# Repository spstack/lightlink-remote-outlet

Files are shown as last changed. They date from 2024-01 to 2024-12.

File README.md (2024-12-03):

# Light Link

A way to remotely link power outlets! This is an idea taken from the "Switcheroo" device that allows taking an existing switched 
power outlet and linking it wirelessly with another outlet. 

Basically, you can change the location of an outlet that is already hooked up to a switch. The device uses a simple 915MHz wireless
transceiver so there's no wifi/bluetooth involved. You just select the channel you want to control and if any device on 
that channel is powered on or off, all of the devices on that channel will follow it.

It's really useful for me in an apartment where you can't change the wiring (or just don't want to). I made about 10 of these devices to
use in multiple locations where there's a switched outlet.

| | | 
|---|---|
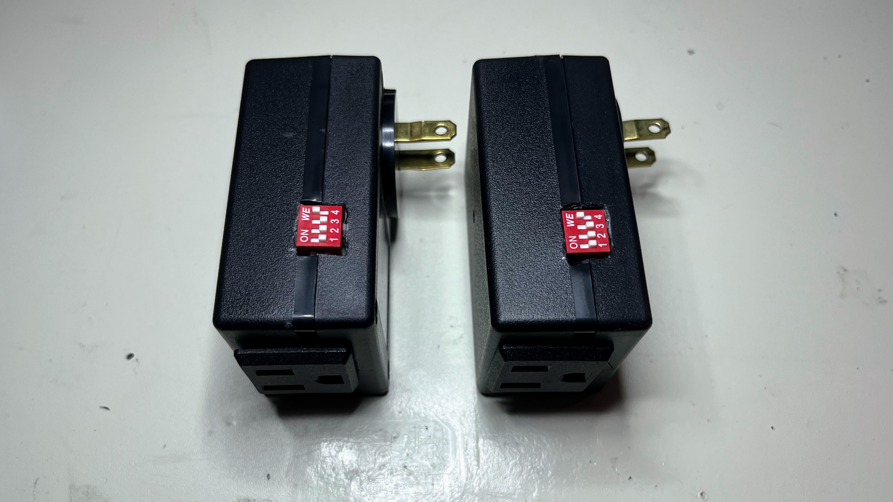
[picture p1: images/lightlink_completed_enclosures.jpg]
Light Link Enclosures
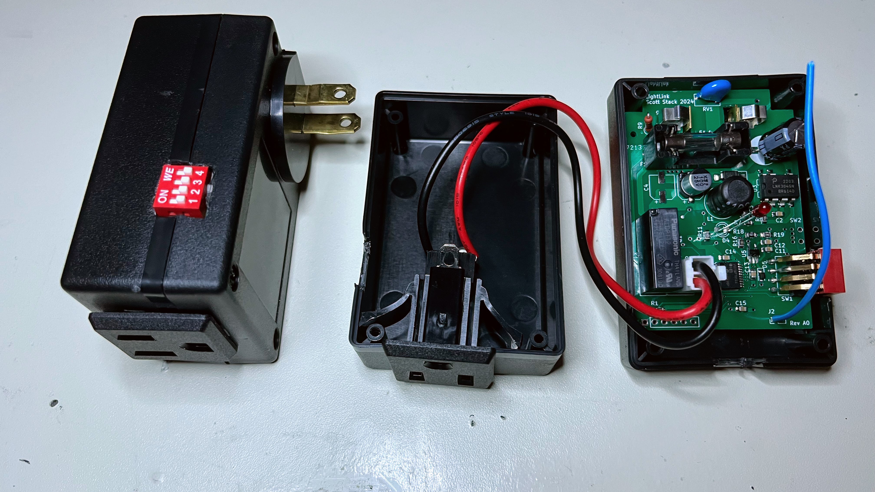
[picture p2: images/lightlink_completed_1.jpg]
Light Link Completed1
| |  |

## Board Design

The board was designed in KiCAD and manufactured by JLC PCB. The main components are a PIC microcontroller connected to an RFM69HCW
wireless transciever. There's also a relay connected to the live end of the incoming mains voltage and a small set of DIP switches for
selecting which channel to transmit on.

The power system is somewhat interesting. A 12V rail is generated through a simple switching regulator that's designed to replace 
capacitive dropper circuits (small amount of current). This rail contains some very large electrolytic capacitors that serve to store energy
and power the rest of the system for a small amount of time when mains voltage is lost. This 12V rail feeds into a second DC-DC switching regulator that powers
the digital electronics. If the 12V rail drops below a threshold, a signal is sent to the PIC to transmit the "power down" command
to all other LightLinks on it's channel.

Schematic Sheet 1 | Schematic Sheet 2 
|-----------------|--------------------|
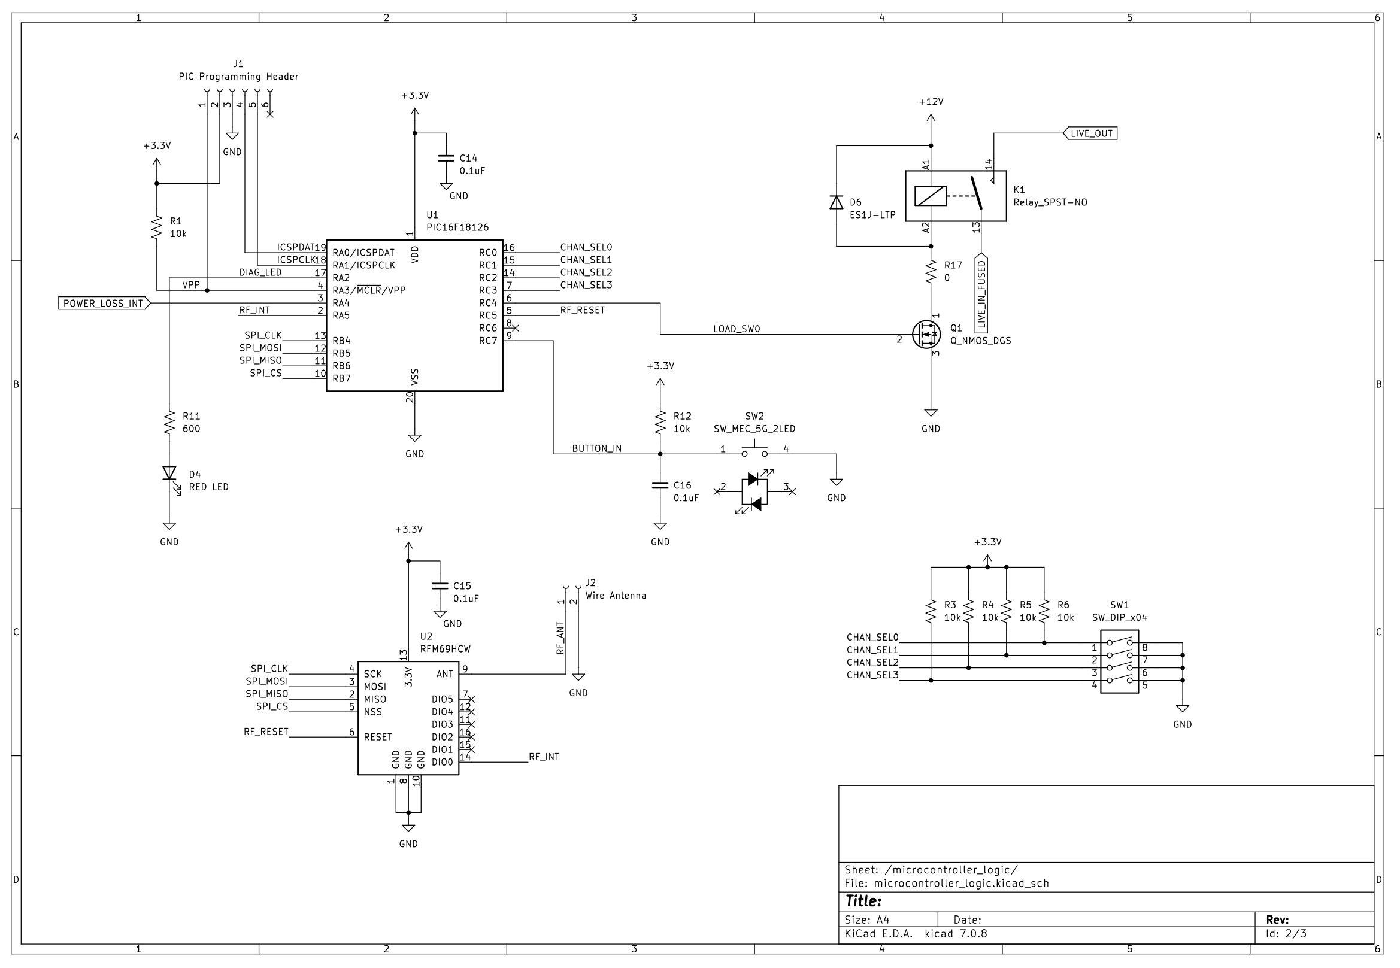
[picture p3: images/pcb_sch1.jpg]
LightLink Sch 1
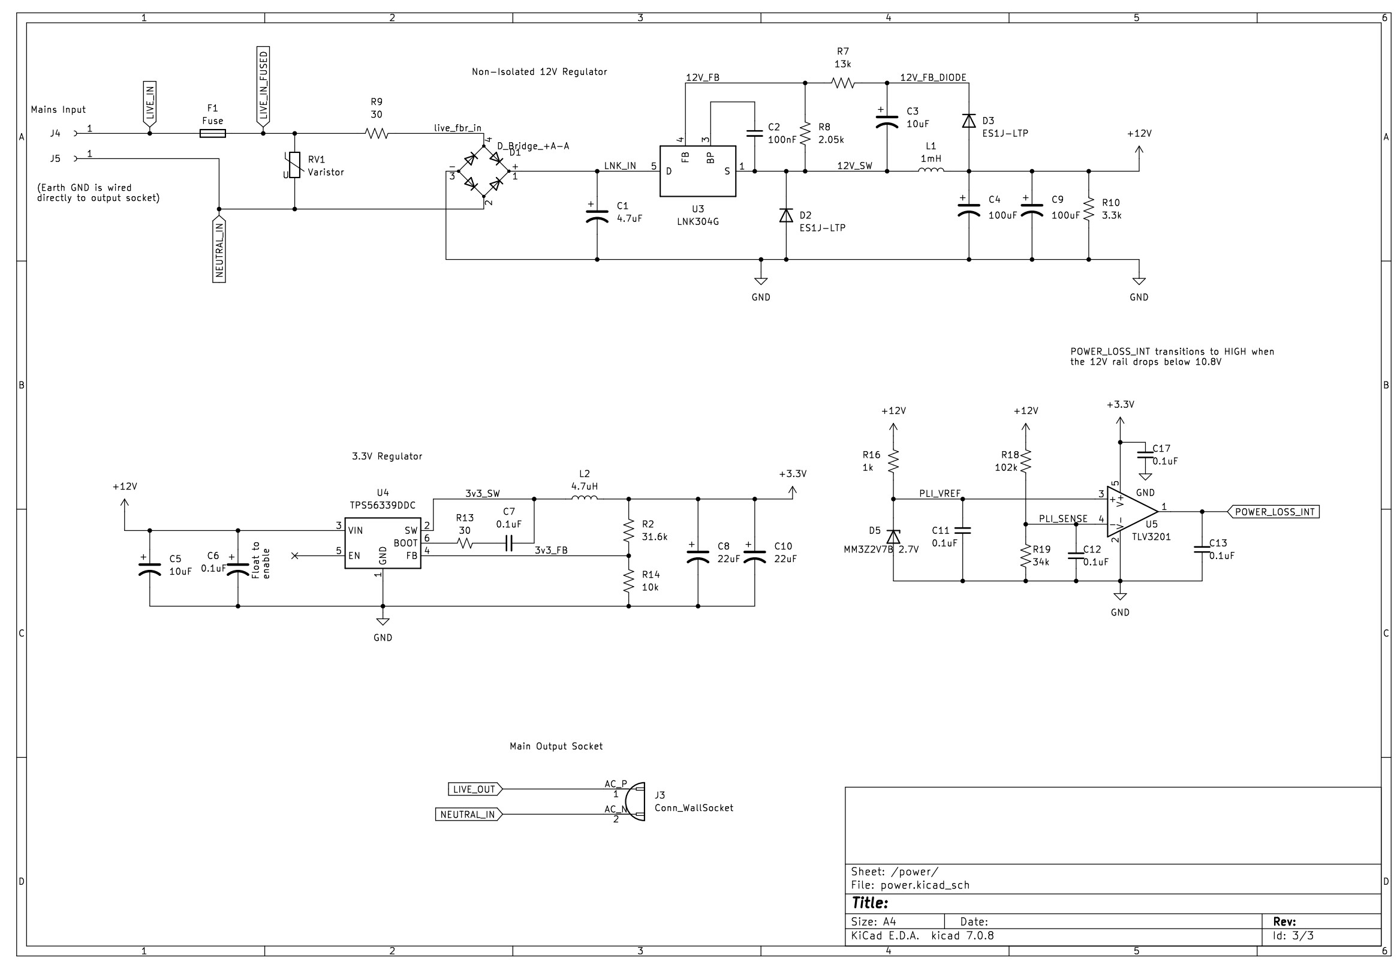
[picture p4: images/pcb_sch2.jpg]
LightLink Sch 2
||  |

Board Layout Front | Board Layout Back 
|-----------------|--------------------|
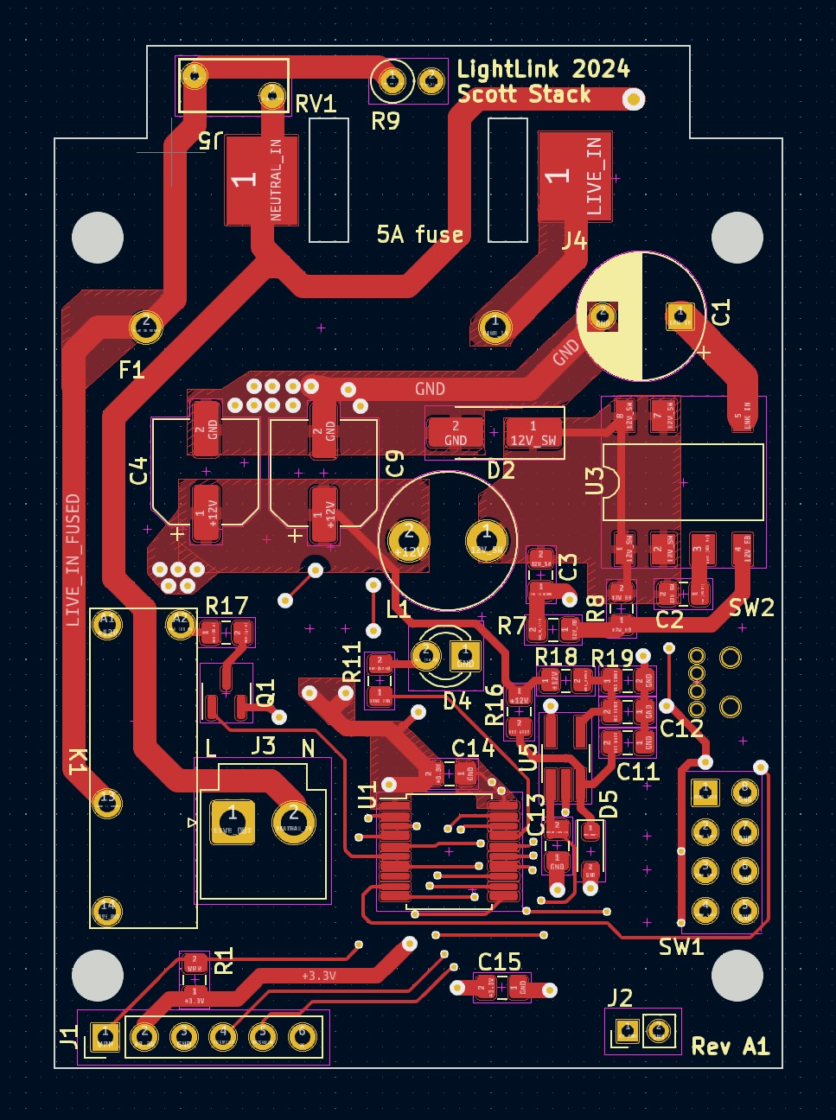
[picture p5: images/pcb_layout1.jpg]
Board Layout 1
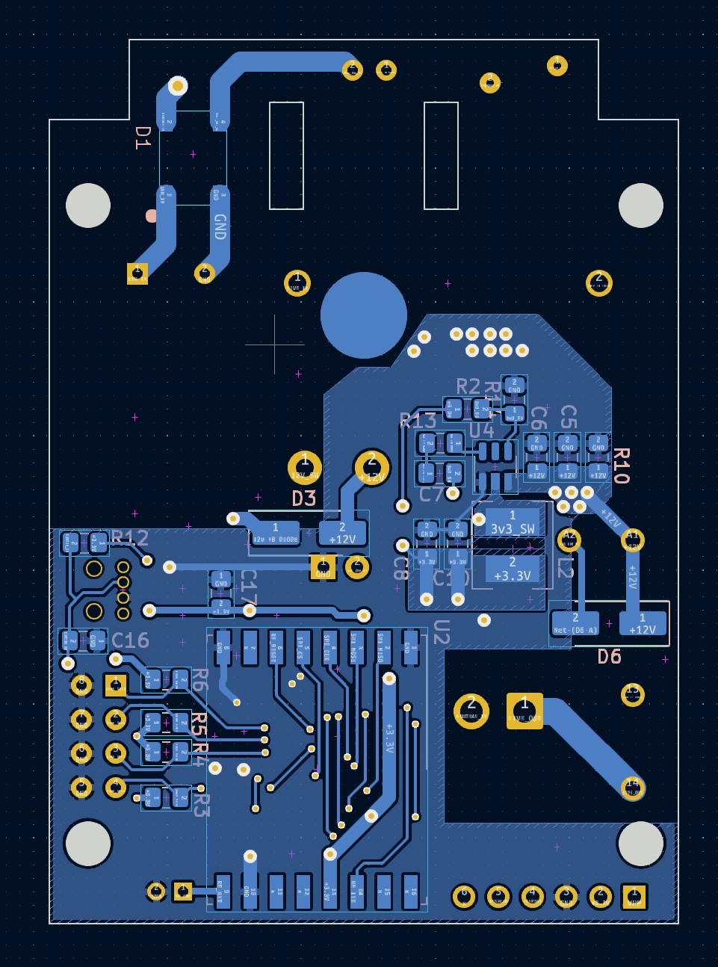
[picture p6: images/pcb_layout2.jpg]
Board Layout 2
| |  |

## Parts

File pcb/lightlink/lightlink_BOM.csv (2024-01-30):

Source: | C:\Users\Scott\Dropbox\my documents\Projects_and_Misc_Tech\1_PROJECTS\RF_OutletRemote\RemoteOutlet\RemoteOutlet.kicad_sch
Date: | 1/25/2024 11:15:09 PM
Tool: | Eeschema 7.0.8
Generator: | C:\Program Files\KiCad\7.0\bin\scripting\plugins/bom_csv_grouped_by_value.py
Component Count: | 58
Collated Components:
Item | Qty | Reference(s) | Value | LibPart | Footprint | Datasheet | DNP | ForwardVoltageDrop | PN | Part | Sim.Device | Sim.Library | Sim.Name | Sim.Params | Sim.Pins | Voltage
="1" | 1 | C1 | 4.7uF | Device:C_Polarized_US | Capacitor_THT:CP_Radial_D8.0mm_P5.00mm | ~
="2" | 1 | C2 | 100nF | Device:C_Small | Capacitor_SMD:C_0805_2012Metric_Pad1.18x1.45mm_HandSolder | ~
="3" | 2 | C3, C5 | 10uF | Device:C_Polarized_US | Capacitor_SMD:C_1206_3216Metric_Pad1.33x1.80mm_HandSolder | ~ |  |  |  |  |  |  |  |  |  | 35V
="4" | 2 | C4, C9 | 100uF | Device:C_Polarized_US | Capacitor_SMD:CP_Elec_6.3x7.7 | ~ |  |  |  |  |  |  |  |  |  | 35V
="5" | 1 | C6 | 0.1uF | Device:C_Polarized_US | Capacitor_SMD:C_0805_2012Metric_Pad1.18x1.45mm_HandSolder | ~
="6" | 7 | C7, C11, C12, C13, C14, C15, C16 | 0.1uF | Device:C_Small | Capacitor_SMD:C_0805_2012Metric_Pad1.18x1.45mm_HandSolder | ~
="7" | 2 | C8, C10 | 22uF | Device:C_Polarized_US | Capacitor_SMD:C_0805_2012Metric_Pad1.18x1.45mm_HandSolder | ~
="8" | 1 | D1 | D_Bridge_+A-A | Device:D_Bridge_+A-A | q_packages_sps:SOPA-4 | ~
="9" | 1 | D2 | ~ | Device:D | Diode_SMD:D_SMA_Handsoldering | ~ |  |  |  |  | D |  |  |  | 1=K 2=A
="10" | 2 | D3, D6 | S1J-13-F | Device:D | Diode_SMD:D_SMA_Handsoldering | ~ |  |  |  |  | D |  |  |  | 1=K 2=A
="11" | 1 | D4 | RED LED | Device:LED | LED_THT:LED_D3.0mm | ~ |  | 1.8V |  | HLMP1700
="12" | 1 | D5 | 2.7V | Device:D_Zener | Diode_SMD:D_SOD-323_HandSoldering | https://www.onsemi.com/pdf/datasheet/mm3z9v1b-d.pdf |  |  | MM3Z2V7B
="13" | 1 | F1 | Fuse | Device:Fuse | fuse_sps:fuseholder_20x5mm_keystone_4628 | ~
14 | 1 | J1 | PIC Programming Header | Connector:Conn_01x06_Socket | Connector_PinHeader_2.54mm:PinHeader_1x06_P2.54mm_Vertical | ~
15 | 1 | J2 | Wire Antenna | Connector:Conn_01x02_Socket | Connector_PinHeader_2.00mm:PinHeader_1x02_P2.00mm_Vertical | ~
="16" | 1 | J3 | Conn_WallSocket | Connector:Conn_WallSocket | Connector_JST:JST_VH_B2P-VH-B_1x02_P3.96mm_Vertical | ~
="17" | 2 | J4, J5 | Conn_01x01_Socket | Connector:Conn_01x01_Socket | connectors_sps:conn_harwin_S1941-46R | ~
="18" | 1 | K1 | Relay_SPST-NO | Relay:Relay_SPST-NO | relays_sps:relay_SPST_NO_panasonic_ALDP112W | ~
="19" | 1 | L1 | 1mH | Device:L | Inductor_THT:L_Radial_D8.7mm_P5.00mm_Fastron_07HCP | ~
="20" | 1 | L2 | 4.7uH | Device:L | inductors_sps:L_Bourns_SRN5040 | ~ |  |  | SRN5040-4R7M
="21" | 1 | Q1 | Q_NMOS_DGS | Device:Q_NMOS_DGS | q_packages_sps:SOT-23_FDV301 | ~
="22" | 7 | R1, R3, R4, R5, R6, R12, R14 | 10k | Device:R_US | Capacitor_SMD:C_0805_2012Metric_Pad1.18x1.45mm_HandSolder | ~
="23" | 1 | R7 | 13k | Device:R_US | Capacitor_SMD:C_0805_2012Metric_Pad1.18x1.45mm_HandSolder | ~
="24" | 1 | R8 | 2.05k | Device:R_US | Capacitor_SMD:C_0805_2012Metric_Pad1.18x1.45mm_HandSolder | ~
="25" | 1 | R9 | 10 - Fusible | Device:R_US | Resistor_THT:R_Axial_DIN0207_L6.3mm_D2.5mm_P2.54mm_Vertical | ~
="26" | 1 | R10 | 3.3k | Device:R_US | Capacitor_SMD:C_0805_2012Metric_Pad1.18x1.45mm_HandSolder | ~
="27" | 1 | R11 | 600 | Device:R_US | Capacitor_SMD:C_0805_2012Metric_Pad1.18x1.45mm_HandSolder | ~
="28" | 1 | R13 | 30 | Device:R_Small_US | Capacitor_SMD:C_0805_2012Metric_Pad1.18x1.45mm_HandSolder | ~
="29" | 1 | R15 | 31.6k | Device:R_US | Capacitor_SMD:C_0805_2012Metric_Pad1.18x1.45mm_HandSolder | ~
="30" | 1 | R16 | 1k | Device:R_US | Capacitor_SMD:C_0805_2012Metric_Pad1.18x1.45mm_HandSolder | ~
="31" | 1 | R17 | 0 | Device:R_US | Capacitor_SMD:C_0805_2012Metric_Pad1.18x1.45mm_HandSolder | ~
="32" | 1 | R18 | 102k | Device:R_US | Capacitor_SMD:C_0805_2012Metric_Pad1.18x1.45mm_HandSolder | ~
="33" | 1 | R19 | 34k | Device:R_US | Capacitor_SMD:C_0805_2012Metric_Pad1.18x1.45mm_HandSolder | ~
34 | 1 | RV1 | Varistor | Device:Varistor | Varistor:RV_Disc_D7mm_W3.4mm_P5mm | ~ |  |  |  |  | SUBCKT | ${KICAD7_SYMBOL_DIR}/Simulation_SPICE.sp | kicad_builtin_varistor | threshold=1k | 1=A 2=B
="35" | 1 | SW1 | SW_DIP_x04 | Switch:SW_DIP_x04 | Package_DIP:DIP-8_W7.62mm | ~
="36" | 1 | SW2 | SW_MEC_5G_2LED | Switch:SW_MEC_5G_2LED | switches_sps:switch_right_angle_228DD1S1AAFAMSC | http://www.apem.com/int/index.php?controller=attachment&id_attachment=488
="37" | 1 | U1 | PIC16F18126 | PIC_Microcontroller_sps:PIC16F18126 | Package_SO:SSOP-20_5.3x7.2mm_P0.65mm | https://ww1.microchip.com/downloads/aemDocuments/documents/MCU08/ProductDocuments/DataSheets/PIC16F18126-46-Microcontrollers-Data-Sheet-DS40002339.pdf
="38" | 1 | U2 | RFM69HCW | RF_Module:RFM69HCW | RF_Module:HOPERF_RFM69HW | https://www.hoperf.com/data/upload/portal/20181127/5bfcb8284d838.pdf
="39" | 1 | U3 | LNK304G | Regulator_Switching:LNK304G | Package_DIP:PowerIntegrations_SMD-8B | http://www.powerint.com/sites/default/files/product-docs/lnk302_304-306.pdf
40 | 1 | U4 | TPS56339DDC | Regulator_Switching:TPS56339DDC | Package_TO_SOT_SMD:SOT-23-6 | https://www.ti.com/lit/ds/symlink/tps56339.pdf
41 | 1 | U5 | TLV3201 | comparators_sps:TLV3201 | Package_TO_SOT_SMD:TSOT-23-5_HandSoldering

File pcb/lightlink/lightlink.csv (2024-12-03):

# | Reference | Qty | Value | Footprint | DNP
1 | C1 | 1 | 4.7uF | Capacitor_THT:CP_Radial_D8.0mm_P5.00mm
2 | C2 | 1 | 100nF | Capacitor_SMD:C_0805_2012Metric_Pad1.18x1.45mm_HandSolder
3 | C3, C5 | 2 | 10uF | Capacitor_SMD:C_0805_2012Metric_Pad1.18x1.45mm_HandSolder
4 | C4, C9 | 2 | 100uF | Capacitor_SMD:CP_Elec_6.3x7.7
5 | C6, C7, C11, C12, C13, C14, C15, C16, C17 | 9 | 0.1uF | Capacitor_SMD:C_0805_2012Metric_Pad1.18x1.45mm_HandSolder
6 | C8, C10 | 2 | 22uF | Capacitor_SMD:C_0805_2012Metric_Pad1.18x1.45mm_HandSolder
7 | D1 | 1 | D_Bridge_+A-A | q_packages_sps:SOPA-4
8 | D2 | 1 | ~ | Diode_SMD:D_SMA_Handsoldering
9 | D3, D6 | 2 | S1J-13-F | Diode_SMD:D_SMA_Handsoldering
10 | D4 | 1 | RED LED | LED_THT:LED_D3.0mm
11 | D5 | 1 | MM3Z2V7B 2.7V | Diode_SMD:D_SOD-323_HandSoldering
12 | F1 | 1 | Fuse | fuse_sps:fuseholder_20x5mm_keystone_4628
13 | J1 | 1 | PIC Programming Header | Connector_PinHeader_2.54mm:PinHeader_1x06_P2.54mm_Vertical
14 | J2 | 1 | Wire Antenna | Connector_PinHeader_2.00mm:PinHeader_1x02_P2.00mm_Vertical
15 | J3 | 1 | Conn_WallSocket | Connector_JST:JST_VH_B2P-VH-B_1x02_P3.96mm_Vertical
16 | J4, J5 | 2 | Conn_01x01_Socket | connectors_sps:conn_harwin_S1941-46R
17 | K1 | 1 | Relay_SPST-NO | relays_sps:relay_SPST_NO_panasonic_ALDP112W
18 | L1 | 1 | 1mH | Inductor_THT:L_Radial_D8.7mm_P5.00mm_Fastron_07HCP
19 | L2 | 1 | 4.7uH | inductors_sps:L_Bourns_SRN5040
20 | Q1 | 1 | Q_NMOS_DGS | q_packages_sps:SOT-23_FDV301
21 | R1, R3, R4, R5, R6, R12, R14 | 7 | 10k | Capacitor_SMD:C_0805_2012Metric_Pad1.18x1.45mm_HandSolder
22 | R2 | 1 | 31.6k | Capacitor_SMD:C_0805_2012Metric_Pad1.18x1.45mm_HandSolder
23 | R7 | 1 | 13k | Capacitor_SMD:C_0805_2012Metric_Pad1.18x1.45mm_HandSolder
24 | R8 | 1 | 2.05k | Capacitor_SMD:C_0805_2012Metric_Pad1.18x1.45mm_HandSolder
25 | R9 | 1 | 30 | Resistor_THT:R_Axial_DIN0207_L6.3mm_D2.5mm_P2.54mm_Vertical
26 | R10 | 1 | 3.3k | Capacitor_SMD:C_0805_2012Metric_Pad1.18x1.45mm_HandSolder
27 | R11 | 1 | 600 | Capacitor_SMD:C_0805_2012Metric_Pad1.18x1.45mm_HandSolder
28 | R13 | 1 | 30 | Capacitor_SMD:C_0805_2012Metric_Pad1.18x1.45mm_HandSolder
29 | R16 | 1 | 1k | Capacitor_SMD:C_0805_2012Metric_Pad1.18x1.45mm_HandSolder
30 | R17 | 1 | 0 | Capacitor_SMD:C_0805_2012Metric_Pad1.18x1.45mm_HandSolder
31 | R18 | 1 | 102k | Capacitor_SMD:C_0805_2012Metric_Pad1.18x1.45mm_HandSolder
32 | R19 | 1 | 34k | Capacitor_SMD:C_0805_2012Metric_Pad1.18x1.45mm_HandSolder
33 | RV1 | 1 | Varistor | Varistor:RV_Disc_D7mm_W3.4mm_P5mm
34 | SW1 | 1 | SW_DIP_x04 | switches_sps:DIP-8_SW_Horiz_Werth
35 | SW2 | 1 | SW_MEC_5G_2LED | switches_sps:switch_right_angle_228DD1S1AAFAMSC
36 | U1 | 1 | PIC16F18126 | Package_SO:SSOP-20_5.3x7.2mm_P0.65mm
37 | U2 | 1 | RFM69HCW | RF_Module:HOPERF_RFM69HW
38 | U3 | 1 | LNK304G | Package_DIP:PowerIntegrations_SMD-8B
39 | U4 | 1 | TPS56339DDC | Package_TO_SOT_SMD:SOT-23-6
40 | U5 | 1 | TLV3201 | Package_TO_SOT_SMD:TSOT-23-5_HandSoldering

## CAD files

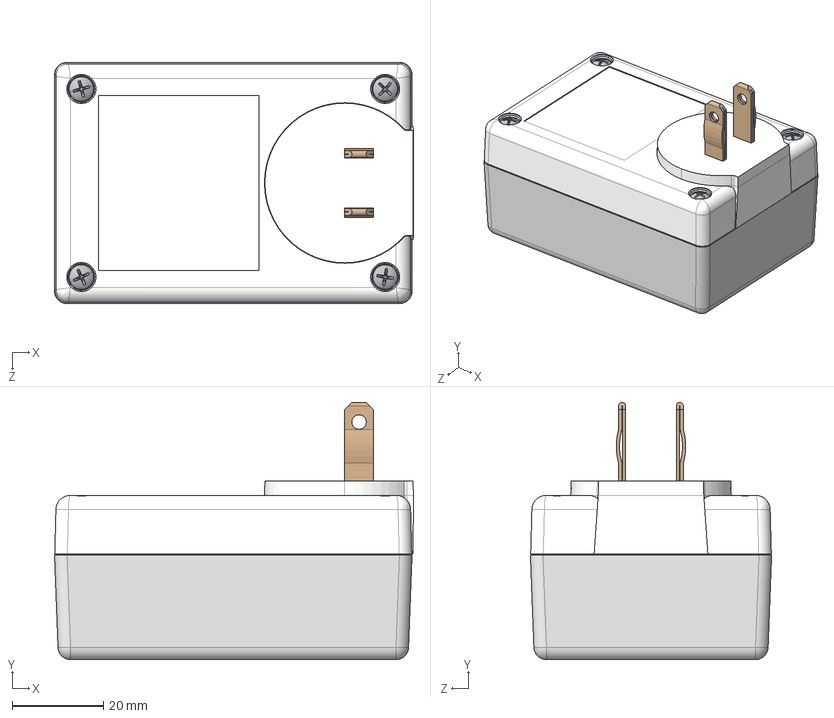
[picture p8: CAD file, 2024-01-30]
models/enclosure_models/PM2314T02XNT.STEP
78.8 x 56.5 x 53.0 mm
SCREWS-HL1-BR x 4
TS-2309B_TS-2309BP
MPB2305_MPB23052NT
BLADES x 2
WELD DISC-PS-BK

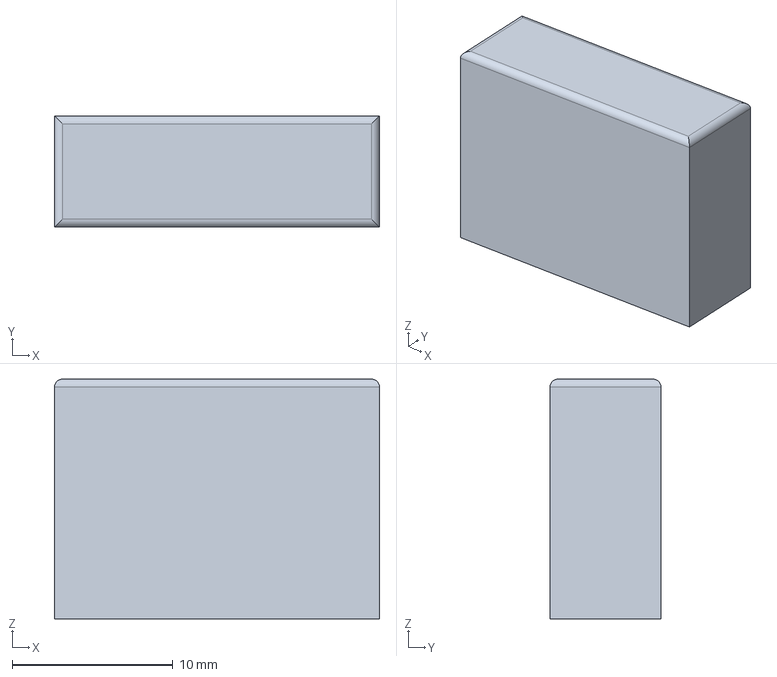
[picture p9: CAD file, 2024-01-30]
pcb/lightlink/component_models/RelayModel.step
20.2 x 6.90 x 14.9 mm

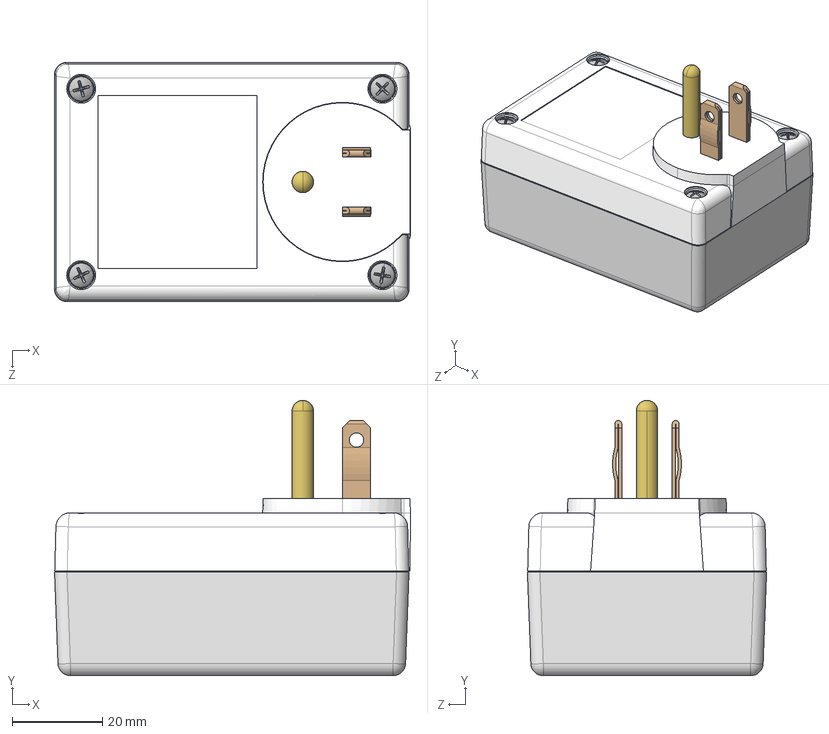
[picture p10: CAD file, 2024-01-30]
models/enclosure_models/PM2314T03XNT.STEP
78.8 x 60.9 x 53.0 mm
TS-2309B_TS-2309BP
SCREWS-HL1-BR x 4
GND-TAB
WELD DISC-PS-BK
BLADES x 2
MPB2305_MPB23053NT
GND-PIN

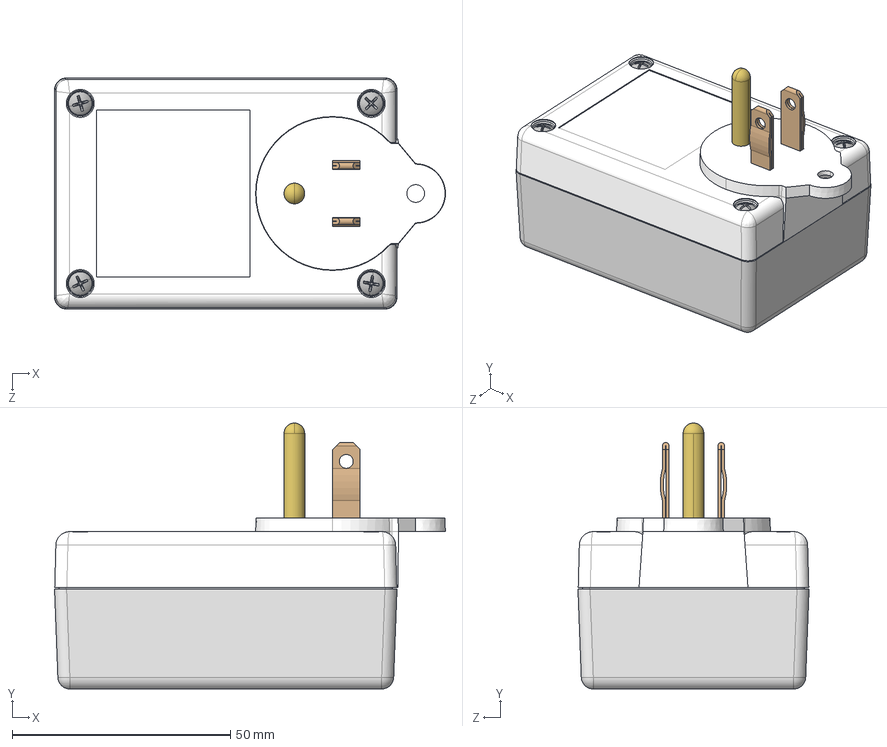
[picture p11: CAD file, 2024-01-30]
models/enclosure_models/PM2314T03XWT.STEP
89.6 x 60.9 x 53.0 mm
TS-2309B_TS-2309BP
MPB2305_MPB23053WT
GND-PIN
GND-TAB
BLADES x 2
WELD DISC-PS-BK
SCREWS-HL1-BR x 4

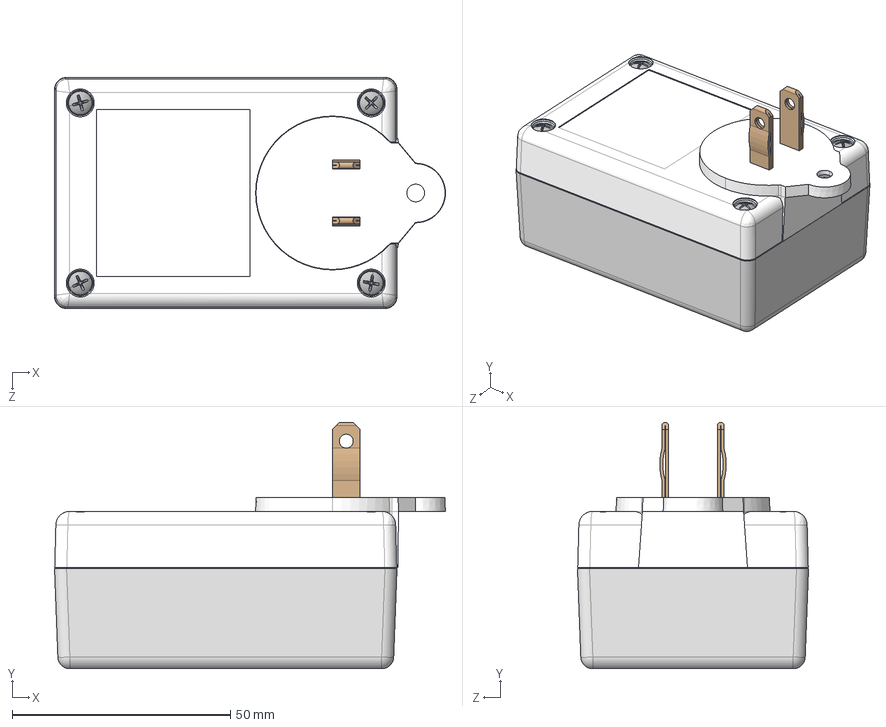
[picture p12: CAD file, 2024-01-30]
models/enclosure_models/PM2314T02XWT.STEP
89.6 x 56.5 x 53.0 mm
SCREWS-HL1-BR x 4
MPB2305_MPB23052WT
BLADES x 2
WELD DISC-PS-BK
TS-2309B_TS-2309BP

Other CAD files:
code/lightlink.X/l.obj

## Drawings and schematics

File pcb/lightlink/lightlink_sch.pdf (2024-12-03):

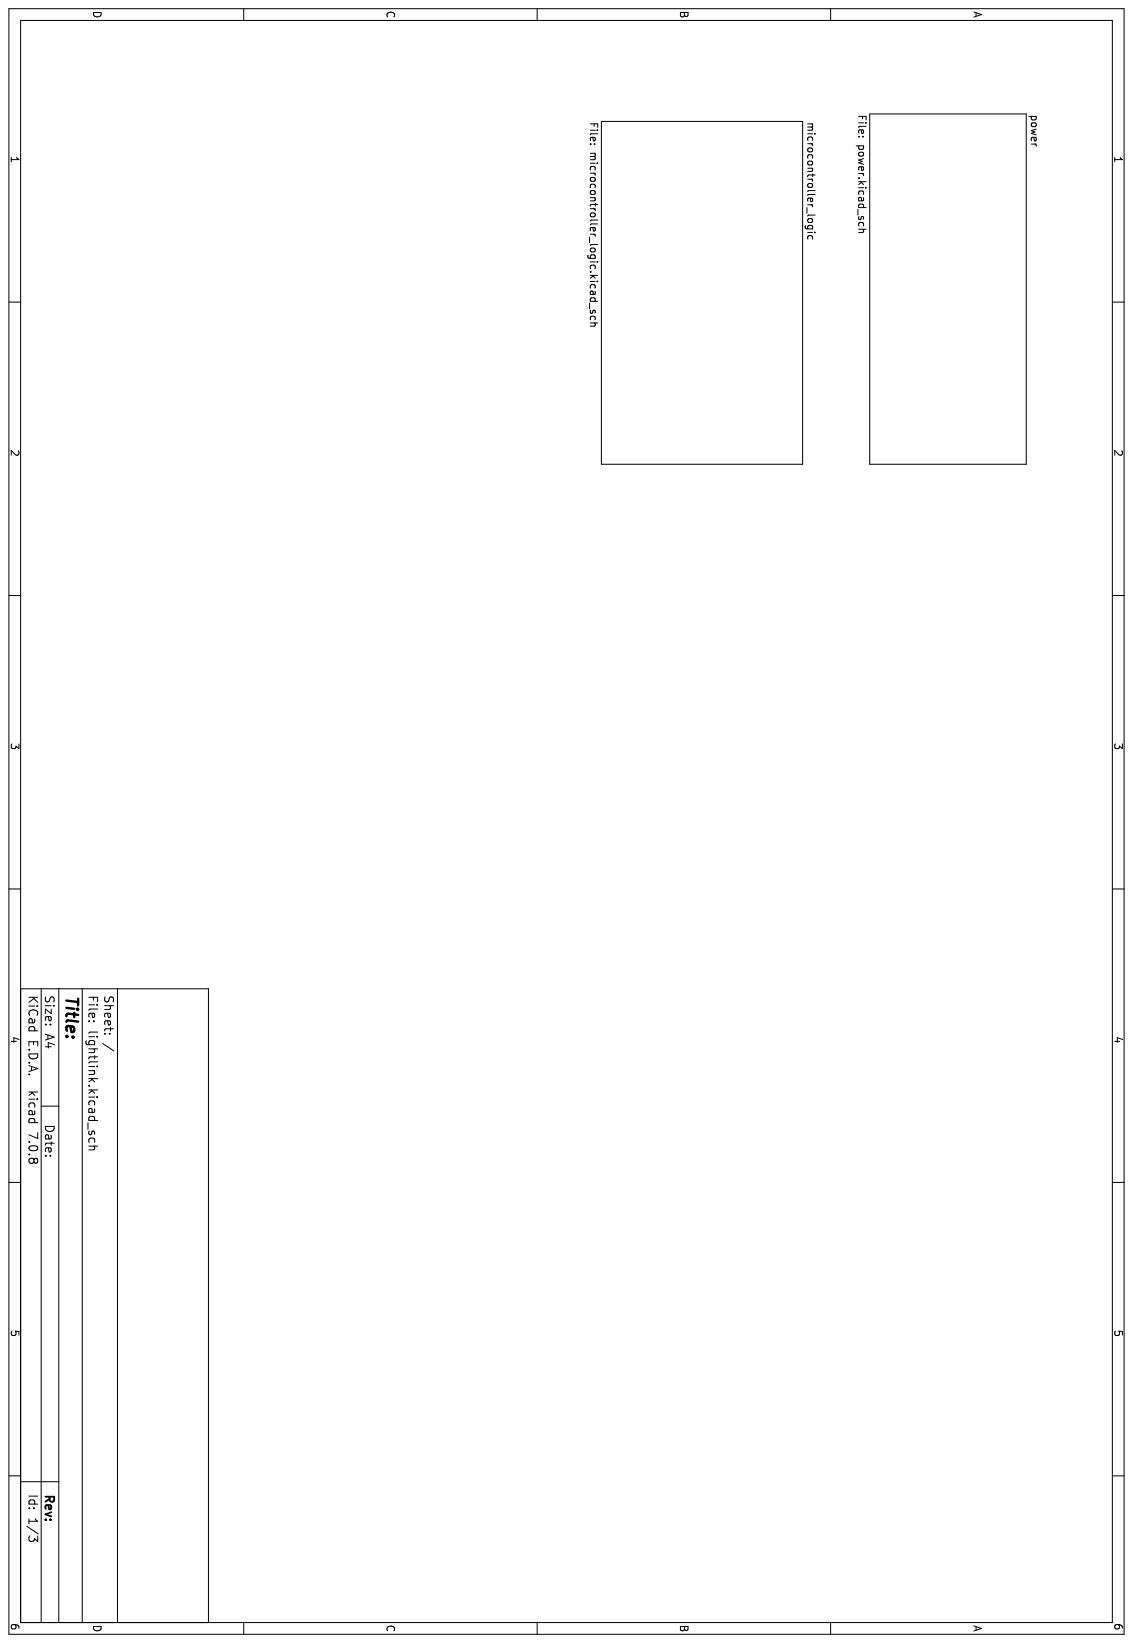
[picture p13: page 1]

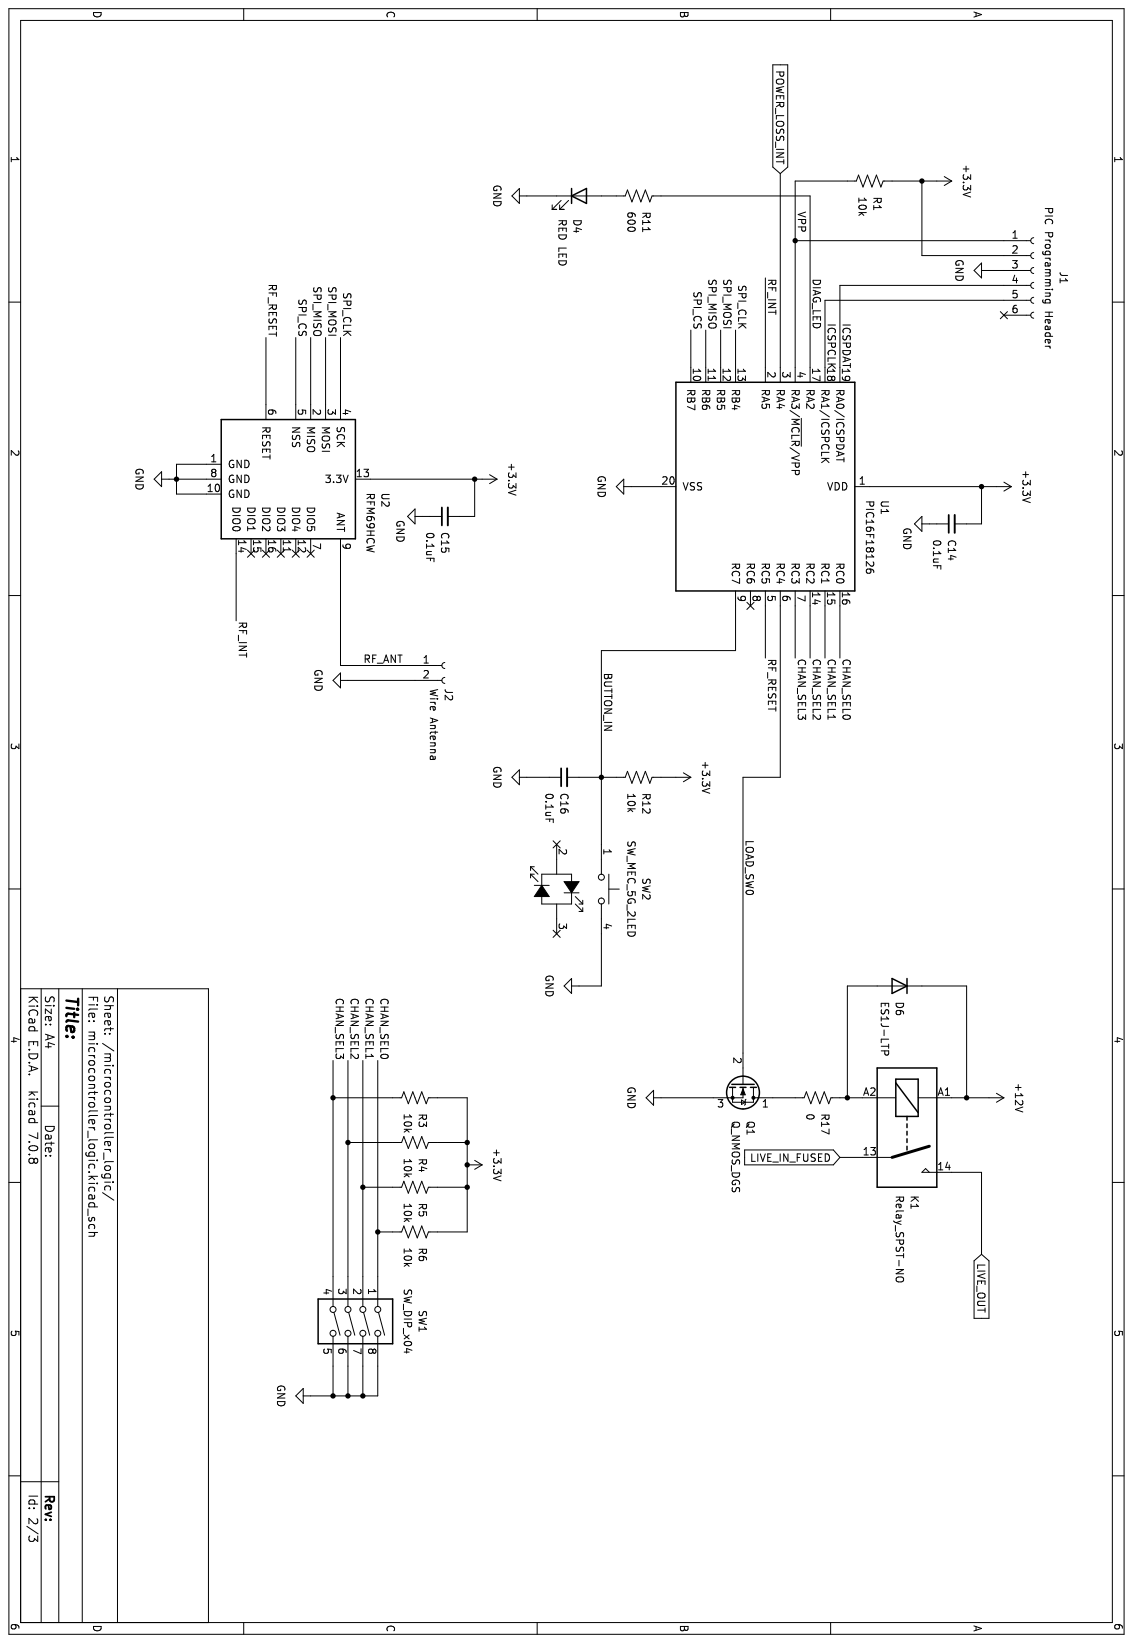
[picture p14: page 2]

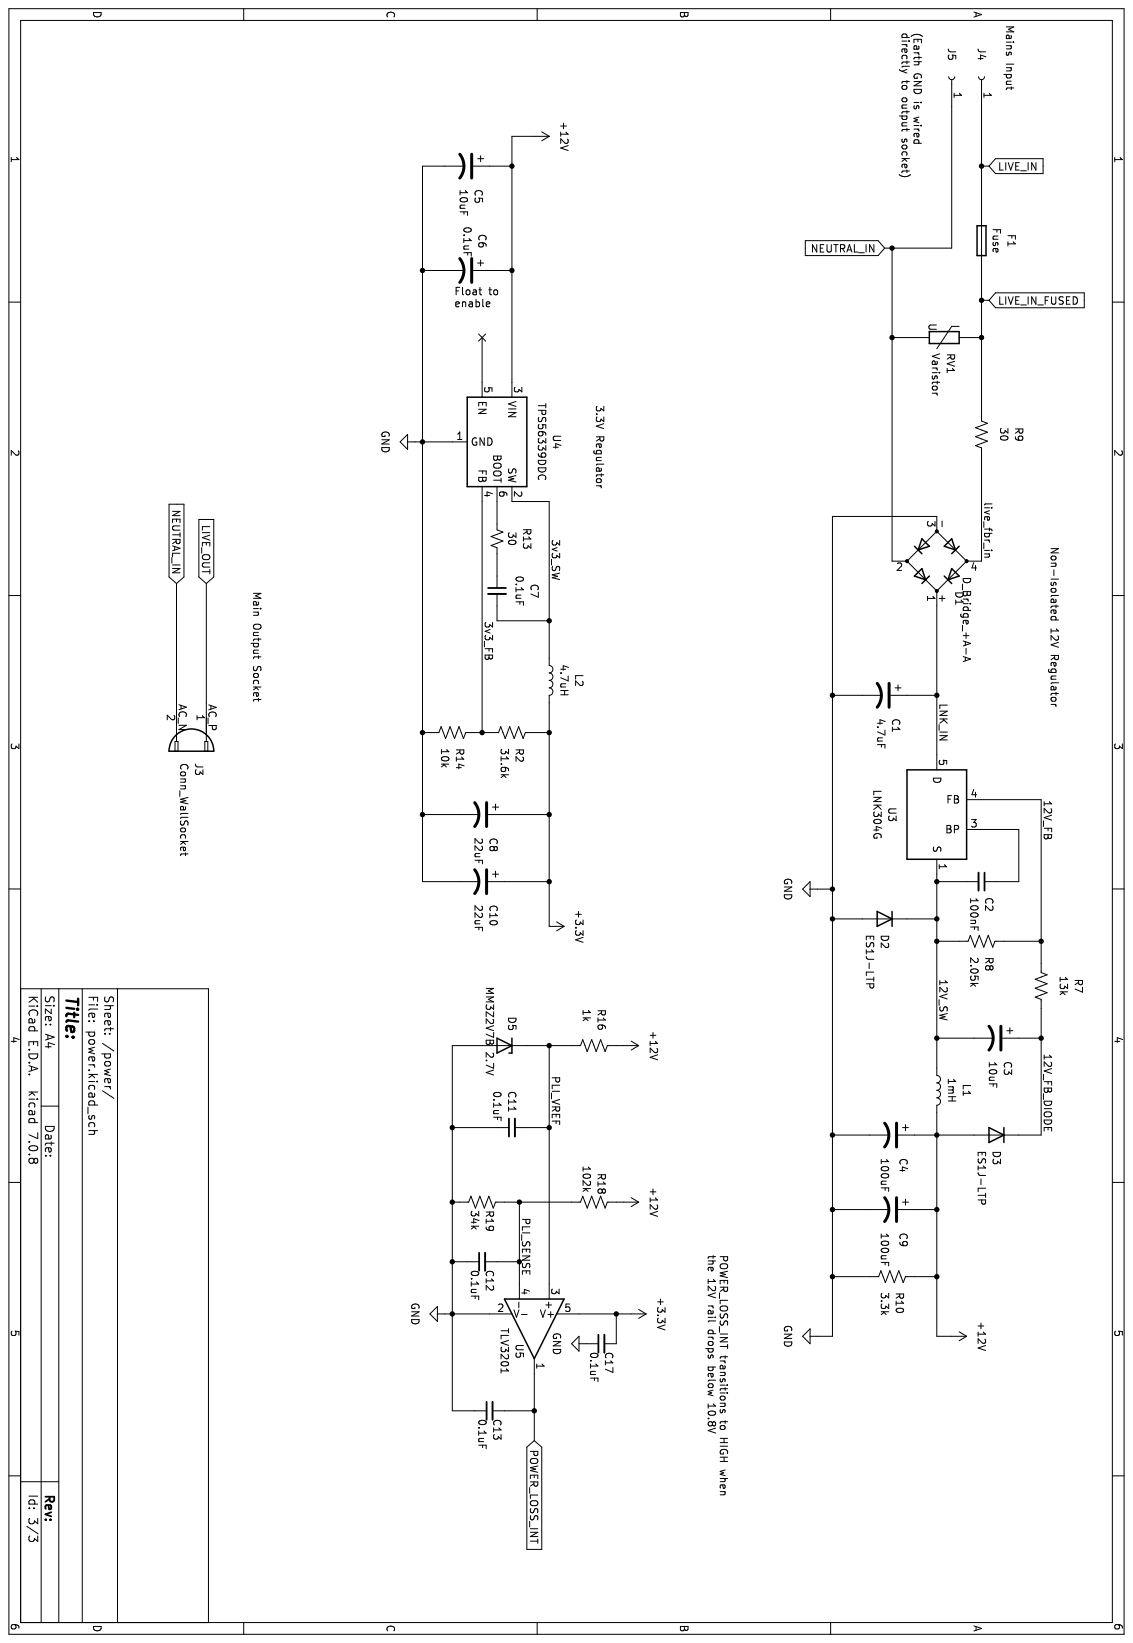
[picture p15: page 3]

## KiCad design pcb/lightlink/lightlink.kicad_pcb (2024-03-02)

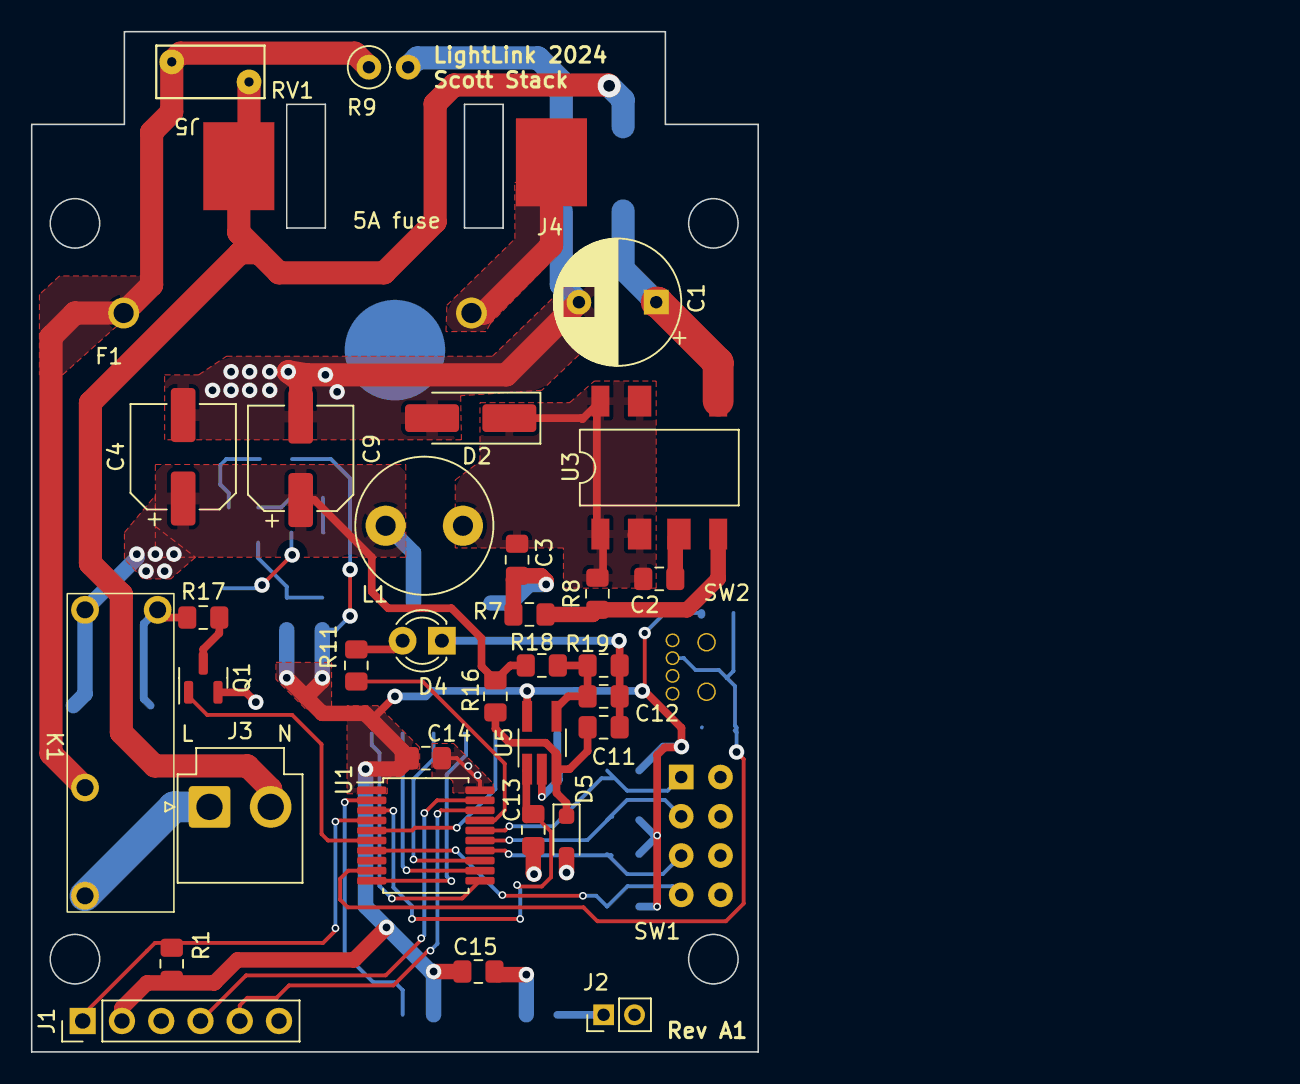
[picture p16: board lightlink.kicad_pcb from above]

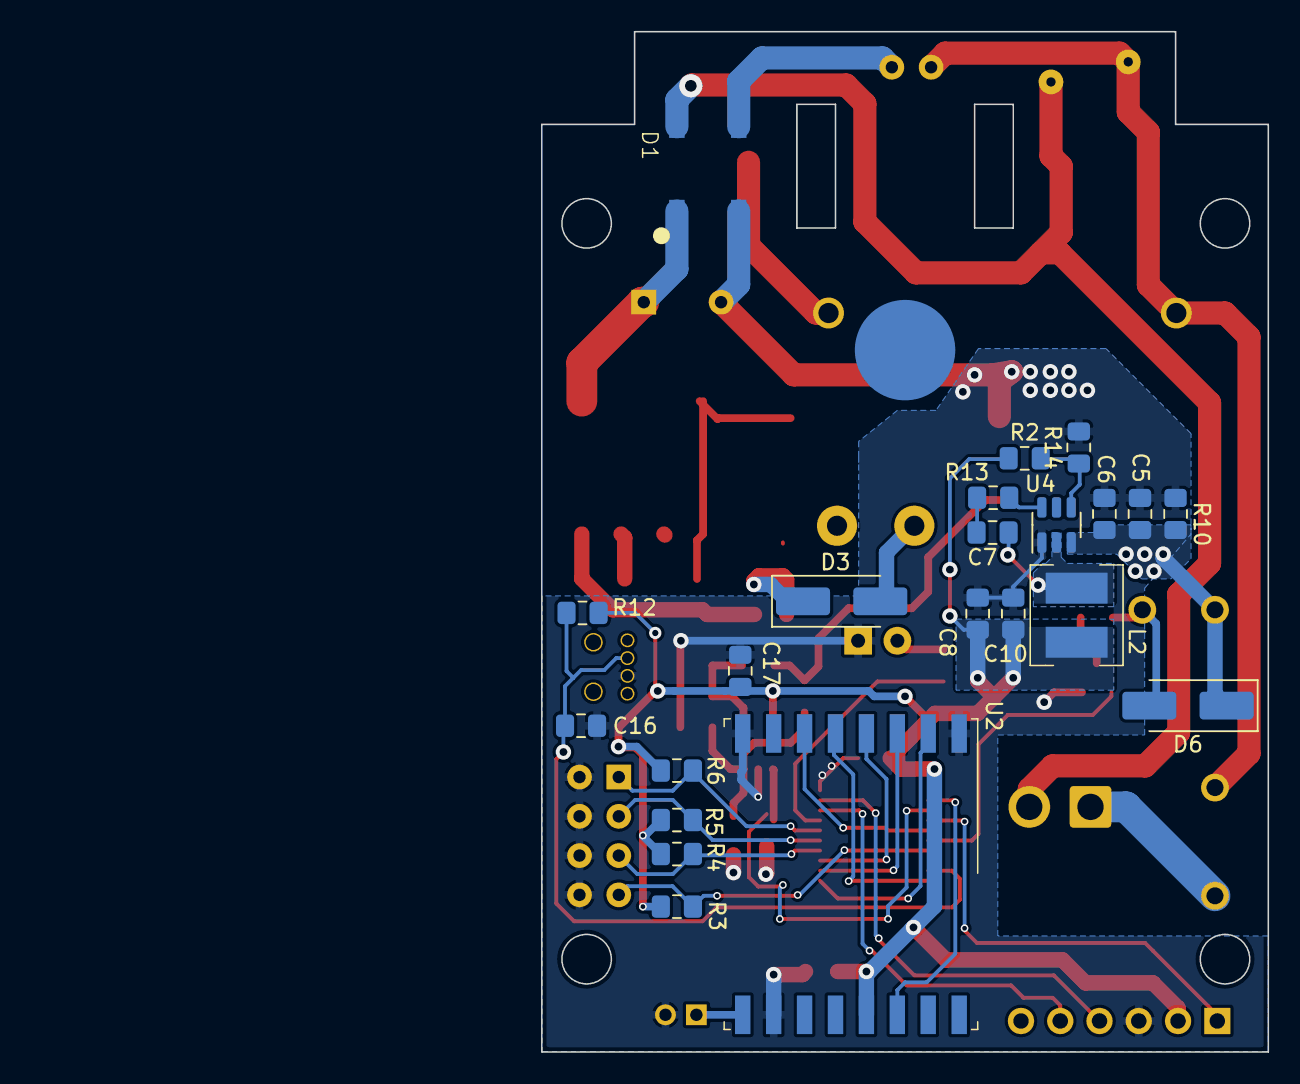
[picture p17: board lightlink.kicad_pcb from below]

Board: 2 copper layers, 47.0 x 66.0 mm, 59 parts (22 on the bottom side), 40 nets.

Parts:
C1: 4.7uF; CP_Radial_D8.0mm_P5.00mm
C2: 100nF; C_0805_2012Metric_Pad1.18x1.45mm_HandSolder
C3, C5: 10uF; C_0805_2012Metric_Pad1.18x1.45mm_HandSolder
C4, C9: 100uF; CP_Elec_6.3x7.7
C6, C7, C11, C12, C13, C14, C15, C16, C17: 0.1uF; C_0805_2012Metric_Pad1.18x1.45mm_HandSolder
C8, C10: 22uF; C_0805_2012Metric_Pad1.18x1.45mm_HandSolder
D1: D_Bridge_+A-A; SOPA-4
D2: D_SMA_Handsoldering
D3, D6: S1J-13-F; D_SMA_Handsoldering
D4: RED LED; LED_D3.0mm
D5: 2.7V; D_SOD-323_HandSoldering
F1: Fuse; fuseholder_20x5mm_keystone_4628
J1: PIC Programming Header; PinHeader_1x06_P2.54mm_Vertical
J2: Wire Antenna; PinHeader_1x02_P2.00mm_Vertical
J3: Conn_WallSocket; JST_VH_B2P-VH-B_1x02_P3.96mm_Vertical
J4, J5: Conn_01x01_Socket; conn_harwin_S1941-46R
K1: Relay_SPST-NO; relay_SPST_NO_panasonic_ALDP112W
L1: 1mH; L_Radial_D8.7mm_P5.00mm_Fastron_07HCP
L2: 4.7uH; L_Bourns_SRN5040
Q1: Q_NMOS_DGS; SOT-23_FDV301
R1, R3, R4, R5, R6, R12, R14: 10k; C_0805_2012Metric_Pad1.18x1.45mm_HandSolder
R2: 31.6k; C_0805_2012Metric_Pad1.18x1.45mm_HandSolder
R7: 13k; C_0805_2012Metric_Pad1.18x1.45mm_HandSolder
R8: 2.05k; C_0805_2012Metric_Pad1.18x1.45mm_HandSolder
R9: 20; R_Axial_DIN0207_L6.3mm_D2.5mm_P2.54mm_Vertical
R10: 3.3k; C_0805_2012Metric_Pad1.18x1.45mm_HandSolder
R11: 600; C_0805_2012Metric_Pad1.18x1.45mm_HandSolder
R13: 30; C_0805_2012Metric_Pad1.18x1.45mm_HandSolder
R16: 1k; C_0805_2012Metric_Pad1.18x1.45mm_HandSolder
R17: 0; C_0805_2012Metric_Pad1.18x1.45mm_HandSolder
R18: 102k; C_0805_2012Metric_Pad1.18x1.45mm_HandSolder
R19: 34k; C_0805_2012Metric_Pad1.18x1.45mm_HandSolder
RV1: Varistor; RV_Disc_D7mm_W3.4mm_P5mm
SW1: SW_DIP_x04; DIP-8_SW_Horiz_Werth
SW2: SW_MEC_5G_2LED; switch_right_angle_228DD1S1AAFAMSC
U1: PIC16F18126; SSOP-20_5.3x7.2mm_P0.65mm
U2: RFM69HCW; HOPERF_RFM69HW
U3: LNK304G; PowerIntegrations_SMD-8B
U4: TPS56339DDC; SOT-23-6
U5: TLV3201; TSOT-23-5_HandSoldering

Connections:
+3.3V: C8.1, C10.1, C14.2, C15.2, C17.2, J1.2, L2.2, R1.1, R2.1, R3.1, R4.1, R5.1, R6.1, R12.1, U1.1 (VDD), U2.13 (3.3V), U5.5 (V+)
+12V: C4.1, C5.1, C6.1, C9.1, D3.2 (A), D6.1 (K), K1.A1, L1.2, R10.1, R16.1, R18.1, U4.3 (VIN)
/microcontroller_logic/BUTTON_IN: C16.2, R12.2, SW2.1 (S1), U1.9 (RC7)
/microcontroller_logic/CHAN_SEL0: R6.2, SW1.1, U1.16 (RC0)
/microcontroller_logic/CHAN_SEL1: R5.2, SW1.2, U1.15 (RC1)
/microcontroller_logic/CHAN_SEL2: R4.2, SW1.3, U1.14 (RC2)
/microcontroller_logic/CHAN_SEL3: R3.2, SW1.4, U1.7 (RC3)
/microcontroller_logic/DIAG_LED: R11.1, U1.17 (RA2)
/microcontroller_logic/ICSPCLK: J1.5, U1.18 (RA1/ICSPCLK)
/microcontroller_logic/ICSPDAT: J1.4, U1.19 (RA0/ICSPDAT)
/microcontroller_logic/LOAD_SW0: Q1.2 (G), U1.6 (RC4)
/microcontroller_logic/RF_ANT: J2.1, U2.9 (ANT)
/microcontroller_logic/RF_INT: U1.2 (RA5), U2.14 (DIO0)
/microcontroller_logic/RF_RESET: U1.5 (RC5), U2.6 (RESET)
/microcontroller_logic/SPI_CLK: U1.13 (RB4), U2.4 (SCK)
/microcontroller_logic/SPI_CS: U1.10 (RB7), U2.5 (NSS)
/microcontroller_logic/SPI_MISO: U1.11 (RB6), U2.2 (MISO)
/microcontroller_logic/SPI_MOSI: U1.12 (RB5), U2.3 (MOSI)
/microcontroller_logic/VPP: J1.1, R1.2, U1.4 (RA3/~MCLR/VPP)
/power/3v3_FB: R2.2, R14.1, U4.4 (FB)
/power/3v3_SW: C7.2, L2.1, U4.2 (SW)
/power/12V_FB: R7.1, R8.1, U3.4 (FB)
/power/12V_FB_DIODE: C3.1, D3.1 (K), R7.2
/power/12V_SW: C2.2, C3.2, D2.1 (K), L1.1, R8.2, U3.1 (S), U3.2 (S), U3.7 (S), U3.8 (S)
/power/LNK_IN: C1.1, D1.1 (+), U3.5 (D)
/power/PLI_SENSE: C12.2, R18.2, R19.1, U5.4 (-)
/power/PLI_VREF: C11.2, D5.1 (K), R16.2, U5.3 (+)
/power/live_fbr_in: D1.4, R9.2
GND: C1.2, C4.2, C5.2, C6.2, C8.2, C9.2, C10.2, C11.1, C12.1, C13.1, C14.1, C15.1, C16.1, C17.1, D1.3 (-), D2.2 (A), D4.1 (K), D5.2 (A), J1.3, J2.2, Q1.3 (S), R10.2, R14.2, R19.2, SW1.5, SW1.6, SW1.7, SW1.8, SW2.4 (S2), U1.20 (VSS), U2.1 (GND), U2.8 (GND), U2.10 (GND), U4.1 (GND), U5.2 (V-)
LIVE_IN: F1.1, J4.1
LIVE_IN_FUSED: F1.2, K1.13, R9.1, RV1.1
LIVE_OUT: J3.1 (AC_P), K1.14
NEUTRAL_IN: D1.2, J3.2 (AC_N), J5.1, RV1.2
unnamed: C7.1, R13.2
unnamed: D4.2 (A), R11.2
unnamed: D6.2 (A), K1.A2, R17.1
unnamed: Q1.1 (D), R17.2
unnamed: C2.1, U3.3 (BP)
unnamed: R13.1, U4.6 (BOOT)
POWER_LOSS_INT: C13.2, U1.3 (RA4), U5.1

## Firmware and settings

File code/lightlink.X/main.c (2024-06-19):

/**
 * @file
 * @brief Main C file for RF controlled outlet
 * @author Scott Stack 
 */

#include <xc.h>
#include "main.h"
#include "config.h"
#include "logging.h"
#include "rfm69/RFM69.h"
#include "timer.h"
#include "remote_actions.h"


// ========== GLOBAL DATA ===========
uint32_t SYSTEM_TICKS = 0;      ///< Global system tick count
global_data_t global_data;      ///< All other global variables stored in structure for clarity             

// ========== LOCAL FUNCTIONS ===========
bool button_is_pressed(void);
void handle_button_input(void);
void process_new_commands(void);
void initialize_global_data(void);
void handle_periodic_msg_send(void);
bool is_hw_ok(void);


// ========== MAIN FUNCTION ===========
void main(void)
{
    int status = NO_ERROR;

    // Init global data structure
    initialize_global_data();

    // Initialize the device
    initialize_peripherals();

    //enable interrupts
    enable_interrupts();

    // Wait to ensure power stabilizes before continuing
    timer_wait_ms(INIT_TIME_WAIT_MS);
    CLRWDT();

    // Switch the attached outlet on right after power is applied
    switch_load(LOAD_ID_OUTLET_0, SWITCH_ON);

    // Initialize the wireless radio
    RFM69_init(RF69_915MHZ, 0, RFM69_DEFAULT_NETWORK_ID);

    // Read the channel code and set it in RFM driver
    global_data.current_channel = read_channel_code_input();
    RFM69_setNodeId(global_data.current_channel);

    // Send the on command to turn on the other switch(s)
    for (int8_t i = 0; i < NUM_INITIAL_RETRIES; i++) {
        status = send_load_switch_cmd(LOAD_ID_OUTLET_0, SWITCH_ON); 
        if (status != NO_ERROR) {
            log_error(DEBUG_LEVEL, status);
        }

        // Wait a random amount of time between 1 and 16 ms before sending again
        timer_wait_ms((uint32_t)rand_lfsr16() & 0xF);

        // Clear the WDT
        CLRWDT();
    }

    // Set the RF module into receive mode by default
    RFM69_enableReceiveMode();

    // Ok to enable power loss interrupts (PLI) now that everything is initialized
    enable_pli_int();

    // Indicate aliveness by flashing DEBUG LED
    // LED_resetIndication();
    
    while (1)
    {
        // Handle all button inputs
        handle_button_input();

        // Check for new commands and process them 
        process_new_commands();

        // Clear the watchdog timer only if hardware is functional
        if (is_hw_ok())
        {
            CLRWDT();
        }
    }
}


/**
 * @brief Initialize the global data structure
*/
void initialize_global_data(void) {
    global_data.time_last_pwron_received = 0;
    global_data.time_last_pwron_sent = 0;
    global_data.poweron_msg_received = false;
    global_data.current_channel = 0;
    global_data.current_switch_val = SWITCH_OFF;

    log_set_log_level(DEFAULT_LOG_LEVEL);
}


/**
 * @brief Function called from main loop to handle all button input
*/
void handle_button_input(void) {
    int status = NO_ERROR;

    // Send a message if a button is pressed
    if (button_is_pressed())
    {
        // Command switch to opposite on whatever we switched it to last time
        global_data.current_switch_val = (global_data.current_switch_val == SWITCH_ON) ? SWITCH_OFF : SWITCH_ON;

        // Set our local switch to new value
        switch_load(LOAD_ID_OUTLET_0, global_data.current_switch_val);

        // Send command to remote to switch states
        status = send_load_switch_cmd(LOAD_ID_OUTLET_0, global_data.current_switch_val); 
        if (status != NO_ERROR)
        {
            log_error(DEBUG_LEVEL, status);
        }

    }

    // Update the channel setting switches
    uint8_t temp_chan = read_channel_code_input();
    if (temp_chan != global_data.current_channel)
    {
        global_data.current_channel = temp_chan;
        RFM69_setNodeId(global_data.current_channel);
    }
}


/**
 * @brief Called from the main function to check for new messages and process them
*/
void process_new_commands(void) {
    uint8_t received_pkt_size = 0;

    // Check to see if there's a received packet, if so handle it
    if(RFM69_receivePacket(global_data.rf_receive_buf, &received_pkt_size, sizeof(global_data.rf_receive_buf)))
    {
        int status = handle_received_command(global_data.rf_receive_buf, received_pkt_size);
        if (status != NO_ERROR) {
            log_error(INFO_LEVEL, status);
        }
    }
}


// ========== SUPPORT FUNCTIONS ===========
uint8_t last_button_input = HIGH;
uint8_t button_state = HIGH;
uint32_t last_debounce_time;
const uint32_t debounce_delay_ms = 50;

bool button_is_pressed(void)
{
    uint8_t reading = BUTTON_PIN;
    bool button_pressed = false;

    // If the button input has changed at all, reset the debounce timer
    if (reading != last_button_input) {
        last_debounce_time = timer_get_ticks();
    }

    // Only sample again if the debounce_delay has elapsed
    if (timer_has_time_elapsed(last_debounce_time, debounce_delay_ms)) {

        if (button_state != reading) {
            // Button input has officially changed!
            button_state = reading;

            // Button has been pressed down if current reading is LOW
            if (reading == LOW) {
                button_pressed = true;
            }
        }
    }

    // Update the last button input with the current reading
    last_button_input = reading;

    return button_pressed;
}
 


/**
 * @brief Read and return the input channel number that we should use
*/
uint8_t read_channel_code_input(void)
{
    // Return the settings on the DIP switch represented as a bitfield
    return ((CHAN_SEL3_PIN << 3) | (CHAN_SEL2_PIN << 2) | (CHAN_SEL1_PIN << 1) | (CHAN_SEL0_PIN));
}


/**
 * @brief Perform a check of the hardware to ensure everything's alright
 */
bool is_hw_ok(void)
{
    return true;
}

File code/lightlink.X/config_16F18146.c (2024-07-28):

/**
 * @brief Device configuration bits and configuration code for the PIC16F18146 microcontroller
 * @author Scott Stack
*/
#include <xc.h>
#include "config_16F18146.h"
#include "main.h"
#include "timer.h"
#include "uart.h"
#include "logging.h"

// CONFIG1
#pragma config FEXTOSC = OFF    // External Oscillator Selection bits (Oscillator not enabled)
#pragma config RSTOSC = HFINTOSC_16MHz// Reset Oscillator Selection bits (HFINTOSC (16 MHz))
#pragma config CLKOUTEN = OFF   // Clock Out Enable bit (CLKOUT function is disabled; i/o or oscillator function on OSC2)
#pragma config CSWEN = ON       // Clock Switch Enable bit (Writing to NOSC and NDIV is allowed)
#pragma config VDDAR = HI       // VDD Range Analog Calibration Selection bit (Internal analog systems are calibrated for operation between VDD = 2.3 - 5.5V)
#pragma config FCMEN = ON       // Fail-Safe Clock Monitor Enable bit (Fail-Safe Clock Monitor enabled)

// CONFIG2
#pragma config MCLRE = EXTMCLR  // Master Clear Enable bit (If LVP = 0, MCLR pin is MCLR; If LVP = 1, RA3 pin function is MCLR)
#pragma config PWRTS = PWRT_OFF // Power-up Timer Selection bits (PWRT is disabled)
#pragma config LPBOREN = OFF    // Low-Power BOR Enable bit (ULPBOR disabled)
#pragma config BOREN = ON       // Brown-out Reset Enable bits (Brown-out Reset enabled, SBOREN bit is ignored)
#pragma config DACAUTOEN = OFF  // DAC Buffer Automatic Range Select Enable bit (DAC Buffer reference range is determined by the REFRNG bit)
#pragma config BORV = LO        // Brown-out Reset Voltage Selection bit (Brown-out Reset Voltage (VBOR) set to 1.9V)
#pragma config ZCD = OFF        // ZCD Disable bit (ZCD module is disabled; ZCD can be enabled by setting the ZCDSEN bit of ZCDCON)
#pragma config PPS1WAY = OFF    // PPSLOCKED One-Way Set Enable bit (The PPSLOCKED bit can be set and cleared as needed (unlocking sequence is required))
#pragma config STVREN = OFF     // Stack Overflow/Underflow Reset Enable bit (Stack Overflow or Underflow will not cause a reset)
#pragma config DEBUG = OFF      // Background Debugger (Background Debugger disabled)

// CONFIG3
#pragma config WDTCPS = WDTCPS_31// WDT Period Select bits (Divider ratio 1:65536; software control of WDTPS)
#pragma config WDTE = ON        // WDT Operating Mode bits (WDT enabled regardless of Sleep; SEN bit is ignored)
#pragma config WDTCWS = WDTCWS_7// WDT Window Select bits (window always open (100%); software control; keyed access not required)
#pragma config WDTCCS = LFINTOSC// WDT Input Clock Select bits (WDT reference clock is the 31.0 kHz LFINTOSC)

// CONFIG4
#pragma config BBSIZE = BB512   // Boot Block Size Selection bits (512 words boot block size)
#pragma config BBEN = OFF       // Boot Block Enable bit (Boot Block disabled)
#pragma config SAFEN = OFF      // Storage Area Flash (SAF) Enable bit (SAF disabled)
#pragma config WRTAPP = OFF     // Application Block Write Protection bit (Application Block is NOT write protected)
#pragma config WRTB = OFF       // Boot Block Write Protection bit (Boot Block is NOT write protected)
#pragma config WRTC = OFF       // Configuration Register Write Protection bit (Configuration Register is NOT write protected)
#pragma config WRTD = OFF       // Data EEPROM Write Protection bit (Data EEPROM is NOT write protected)
#pragma config WRTSAF = OFF     // Storage Area Flash (SAF) Write Protection bit (SAF is NOT write protected)
#pragma config LVP = ON         // Low Voltage Programming Enable bit (Low Voltage programming enabled. MCLR/Vpp pin function is MCLR. MCLRE Configuration bit is ignored)

// CONFIG5
#pragma config CP = OFF         // Program Flash Memory Code Protection bit (Program Flash Memory code protection is disabled)
#pragma config CPD = OFF        // Data EEPROM Code Protection bit (Data EEPROM code protection is disabled)

// #pragma config statements should precede project file includes.
// Use project enums instead of #define for ON and OFF.

// Random number generator seed
static uint16_t _rand_seed;


/**
 * @brief initialize all peripherals
*/
void initialize_peripherals(void)
{
    init_oscillator();
    
    init_GPIOs();

    init_SPI();
    
    init_timers();

    init_UART();

    rand_lfsr_seed(rand_sample_adc());
}


/**
 * @brief initialize oscillator module(s)
*/
void init_oscillator(void)
{
    // Nothing to do for now
}

void enable_interrupts(void)
{
    INTCONbits.GIE = 1;
    INTCONbits.PEIE = 1;
}

void disable_interrupts(void)
{
    INTCONbits.GIE = 0;
    INTCONbits.PEIE = 0;
}

void enable_pli_int(void)
{
    PLI_IOC_EN = 1;
    PIE0bits.IOCIE = 1; //enable interrupt on change module
}

void disable_pli_int(void)
{
    PLI_IOC_EN = 0;
    PIE0bits.IOCIE = 0;
}
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

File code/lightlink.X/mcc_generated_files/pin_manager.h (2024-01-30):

/**
  @Generated Pin Manager Header File

  @Company:
    Microchip Technology Inc.

  @File Name:
    pin_manager.h

  @Summary:
    This is the Pin Manager file generated using MPLAB(c) Code Configurator

  @Description:
    This header file provides implementations for pin APIs for all pins selected in the GUI.
    Generation Information :
        Product Revision  :  MPLAB(c) Code Configurator - 4.85.1
        Device            :  PIC16LF1455
        Version           :  1.01
    The generated drivers are tested against the following:
        Compiler          :  XC8 1.35
        MPLAB             :  MPLAB X 3.40

    Copyright (c) 2013 - 2015 released Microchip Technology Inc.  All rights reserved.

    Microchip licenses to you the right to use, modify, copy and distribute
    Software only when embedded on a Microchip microcontroller or digital signal
    controller that is integrated into your product or third party product
    (pursuant to the sublicense terms in the accompanying license agreement).

    You should refer to the license agreement accompanying this Software for
    additional information regarding your rights and obligations.

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
*/


#ifndef PIN_MANAGER_H
#define PIN_MANAGER_H

#define INPUT   1
#define OUTPUT  0

#define HIGH    1
#define LOW     0

#define ANALOG      1
#define DIGITAL     0

#define PULL_UP_ENABLED      1
#define PULL_UP_DISABLED     0

// get/set BUTTON_INPUT aliases
#define BUTTON_INPUT_PORT               PORTAbits.RA0
#define BUTTON_INPUT_GetValue()           PORTAbits.RA0

// get/set nIRQ aliases
#define nIRQ_PORT               PORTAbits.RA1
#define nIRQ_GetValue()           PORTAbits.RA1

// get/set IO_RA4 aliases
#define IO_RA4_TRIS               TRISAbits.TRISA4
#define IO_RA4_LAT                LATAbits.LATA4
#define IO_RA4_PORT               PORTAbits.RA4
#define IO_RA4_WPU                WPUAbits.WPUA4
#define IO_RA4_ANS                ANSELAbits.ANSA4
#define IO_RA4_SetHigh()            do { LATAbits.LATA4 = 1; } while(0)
#define IO_RA4_SetLow()             do { LATAbits.LATA4 = 0; } while(0)
#define IO_RA4_Toggle()             do { LATAbits.LATA4 = ~LATAbits.LATA4; } while(0)
#define IO_RA4_GetValue()           PORTAbits.RA4
#define IO_RA4_SetDigitalInput()    do { TRISAbits.TRISA4 = 1; } while(0)
#define IO_RA4_SetDigitalOutput()   do { TRISAbits.TRISA4 = 0; } while(0)
#define IO_RA4_SetPullup()      do { WPUAbits.WPUA4 = 1; } while(0)
#define IO_RA4_ResetPullup()    do { WPUAbits.WPUA4 = 0; } while(0)
#define IO_RA4_SetAnalogMode()  do { ANSELAbits.ANSA4 = 1; } while(0)
#define IO_RA4_SetDigitalMode() do { ANSELAbits.ANSA4 = 0; } while(0)

// get/set LOAD_SWITCH aliases
#define LOAD_SWITCH_TRIS               TRISAbits.TRISA5
#define LOAD_SWITCH_LAT                LATAbits.LATA5
#define LOAD_SWITCH_PORT               PORTAbits.RA5
#define LOAD_SWITCH_WPU                WPUAbits.WPUA5
#define LOAD_SWITCH_SetHigh()            do { LATAbits.LATA5 = 1; } while(0)
#define LOAD_SWITCH_SetLow()             do { LATAbits.LATA5 = 0; } while(0)
#define LOAD_SWITCH_Toggle()             do { LATAbits.LATA5 = ~LATAbits.LATA5; } while(0)
#define LOAD_SWITCH_GetValue()           PORTAbits.RA5
#define LOAD_SWITCH_SetDigitalInput()    do { TRISAbits.TRISA5 = 1; } while(0)
#define LOAD_SWITCH_SetDigitalOutput()   do { TRISAbits.TRISA5 = 0; } while(0)
#define LOAD_SWITCH_SetPullup()      do { WPUAbits.WPUA5 = 1; } while(0)
#define LOAD_SWITCH_ResetPullup()    do { WPUAbits.WPUA5 = 0; } while(0)

// get/set SCK aliases
#define SCK_TRIS               TRISCbits.TRISC0
#define SCK_LAT                LATCbits.LATC0
#define SCK_PORT               PORTCbits.RC0
#define SCK_ANS                ANSELCbits.ANSC0
#define SCK_SetHigh()            do { LATCbits.LATC0 = 1; } while(0)
#define SCK_SetLow()             do { LATCbits.LATC0 = 0; } while(0)
#define SCK_Toggle()             do { LATCbits.LATC0 = ~LATCbits.LATC0; } while(0)
#define SCK_GetValue()           PORTCbits.RC0
#define SCK_SetDigitalInput()    do { TRISCbits.TRISC0 = 1; } while(0)
#define SCK_SetDigitalOutput()   do { TRISCbits.TRISC0 = 0; } while(0)
#define SCK_SetAnalogMode()  do { ANSELCbits.ANSC0 = 1; } while(0)
#define SCK_SetDigitalMode() do { ANSELCbits.ANSC0 = 0; } while(0)

// get/set SDI aliases
#define SDI_TRIS               TRISCbits.TRISC1
#define SDI_LAT                LATCbits.LATC1
#define SDI_PORT               PORTCbits.RC1
#define SDI_ANS                ANSELCbits.ANSC1
#define SDI_SetHigh()            do { LATCbits.LATC1 = 1; } while(0)
#define SDI_SetLow()             do { LATCbits.LATC1 = 0; } while(0)
#define SDI_Toggle()             do { LATCbits.LATC1 = ~LATCbits.LATC1; } while(0)
#define SDI_GetValue()           PORTCbits.RC1
#define SDI_SetDigitalInput()    do { TRISCbits.TRISC1 = 1; } while(0)
#define SDI_SetDigitalOutput()   do { TRISCbits.TRISC1 = 0; } while(0)
#define SDI_SetAnalogMode()  do { ANSELCbits.ANSC1 = 1; } while(0)
#define SDI_SetDigitalMode() do { ANSELCbits.ANSC1 = 0; } while(0)

// get/set SDO aliases
#define SDO_TRIS               TRISCbits.TRISC2
#define SDO_LAT                LATCbits.LATC2
#define SDO_PORT               PORTCbits.RC2
#define SDO_ANS                ANSELCbits.ANSC2
#define SDO_SetHigh()            do { LATCbits.LATC2 = 1; } while(0)
#define SDO_SetLow()             do { LATCbits.LATC2 = 0; } while(0)
#define SDO_Toggle()             do { LATCbits.LATC2 = ~LATCbits.LATC2; } while(0)
#define SDO_GetValue()           PORTCbits.RC2
#define SDO_SetDigitalInput()    do { TRISCbits.TRISC2 = 1; } while(0)
#define SDO_SetDigitalOutput()   do { TRISCbits.TRISC2 = 0; } while(0)
#define SDO_SetAnalogMode()  do { ANSELCbits.ANSC2 = 1; } while(0)
#define SDO_SetDigitalMode() do { ANSELCbits.ANSC2 = 0; } while(0)

// get/set DEBUG_LED aliases
#define DEBUG_LED_TRIS               TRISCbits.TRISC3
#define DEBUG_LED_LAT                LATCbits.LATC3
#define DEBUG_LED_PORT               PORTCbits.RC3
#define DEBUG_LED_ANS                ANSELCbits.ANSC3
#define DEBUG_LED_SetHigh()            do { LATCbits.LATC3 = 1; } while(0)
#define DEBUG_LED_SetLow()             do { LATCbits.LATC3 = 0; } while(0)
#define DEBUG_LED_Toggle()             do { LATCbits.LATC3 = ~LATCbits.LATC3; } while(0)
#define DEBUG_LED_GetValue()           PORTCbits.RC3
#define DEBUG_LED_SetDigitalInput()    do { TRISCbits.TRISC3 = 1; } while(0)
#define DEBUG_LED_SetDigitalOutput()   do { TRISCbits.TRISC3 = 0; } while(0)
#define DEBUG_LED_SetAnalogMode()  do { ANSELCbits.ANSC3 = 1; } while(0)
#define DEBUG_LED_SetDigitalMode() do { ANSELCbits.ANSC3 = 0; } while(0)
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

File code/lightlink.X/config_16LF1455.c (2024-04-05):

// CONFIG1
#pragma config FOSC = INTOSC    // Oscillator Selection Bits (INTOSC oscillator: I/O function on CLKIN pin)
#pragma config WDTE = ON        // Watchdog Timer Enable (WDT enabled)
#pragma config PWRTE = OFF      // Power-up Timer Enable (PWRT disabled)
#pragma config MCLRE = ON       // MCLR Pin Function Select (MCLR/VPP pin function is MCLR)
#pragma config CP = OFF         // Flash Program Memory Code Protection (Program memory code protection is disabled)
#pragma config BOREN = ON       // Brown-out Reset Enable (Brown-out Reset enabled)
#pragma config CLKOUTEN = OFF   // Clock Out Enable (CLKOUT function is disabled. I/O or oscillator function on the CLKOUT pin)
#pragma config IESO = ON        // Internal/External Switchover Mode (Internal/External Switchover Mode is enabled)
#pragma config FCMEN = ON       // Fail-Safe Clock Monitor Enable (Fail-Safe Clock Monitor is enabled)

// CONFIG2
#pragma config WRT = OFF        // Flash Memory Self-Write Protection (Write protection off)
#pragma config CPUDIV = CLKDIV3 // CPU System Clock Selection Bit (CPU system clock divided by 3)
#pragma config USBLSCLK = 48MHz // USB Low SPeed Clock Selection bit (System clock expects 48 MHz, FS/LS USB CLKENs divide-by is set to 8.)
#pragma config PLLMULT = 3x     // PLL Multipler Selection Bit (3x Output Frequency Selected)
#pragma config PLLEN = DISABLED // PLL Enable Bit (3x or 4x PLL Disabled)
#pragma config STVREN = ON      // Stack Overflow/Underflow Reset Enable (Stack Overflow or Underflow will cause a Reset)
#pragma config BORV = LO        // Brown-out Reset Voltage Selection (Brown-out Reset Voltage (Vbor), low trip point selected.)
#pragma config LPBOR = OFF      // Low-Power Brown Out Reset (Low-Power BOR is disabled)
#pragma config LVP = ON         // Low-Voltage Programming Enable (Low-voltage programming enabled)

// #pragma config statements should precede project file includes.
// Use project enums instead of #define for ON and OFF.

#include <xc.h>
#include <pic16lf1455.h>
#include "main.h"
#include "config.h"
#include "timer.h"


void initialize_peripherals(void)
{
    init_oscillator();
    
    init_GPIOs();
    
    init_SPI();
    
    init_timers();

    rand_lfsr_seed(rand_sample_adc());
}

void init_oscillator(void)
{
    uint32_t i;

    //choose 16MHz internal Oscillator source
    OSCCONbits.IRCF = 0xF;

    //wait for a little while for clock to stabilize before continuing
    for (i=0; i < 10000; i++);
    
}

void enable_interrupts(void)
{
    INTCONbits.GIE = 1;
    INTCONbits.PEIE = 1;
}

void disable_interrupts(void)
{
    INTCONbits.GIE = 0;
    INTCONbits.PEIE = 0;
}

void enable_pli_int(void)
{
    PLI_IOC_EN = 1;
    INTCONbits.IOCIE = 1; //enable interrupt on change module
}

void init_GPIOs(void)
{
    // Turn off all analog functionality
    ANSELC = 0;
    ANSELA = 0;
    
    DEBUG_LED_TRIS = 0; //set LED to output
    DEBUG_LED_PIN = 0;
    
    RF_CS_TRIS = 0;  //set CS for RF module to output
    RF_CS_PIN = 1;   //set high by default (not active)
    
    RF_RESET_TRIS = 1; // set rf module reset pin to input initially to make it high-Z as referenced in the datasheet

    RF_INT_TRIS = 1; //set RF int pin to input
    //RF_INT_IOC = 1; //set to interrupt on rising edge of RFM69 interrupt pin

    // Setup outlet control pin as output
    LOAD0_TRIS = 0;

    // BUTTON_SENDMSG_TRIS = 1; // Set button pin to input (doesn't exist... always an input)
}


void init_timers(void)
{
    //setup timer 0 to be system clock
    OPTION_REGbits.T0CS = 0;
    OPTION_REGbits.PSA = 0; //select FOSC/4 as clock = 16MHz / 4 = 4MHz
    OPTION_REGbits.PS = 4; //prescalar of 32 = 125kHz
    TMR0 = TIMER_INIT_VALUE_1MS; //initialize TMR0 so that it overflows after 125 ticks @ 125kHz or 1ms
    TMR0IE = 1; //enable timer interrupt
    
    SYSTEM_TICKS = 0;
    
}

void init_SPI(void)
{
    SSPCON1bits.SSPM = 1; //SPI Master mode w/ 1MHz clock (FOSC / 16)
    SSPCON1bits.SSPEN = 1; //enable the serial port
    SSPSTATbits.CKE = 1; // data changes in between clock edges
    
    
    //set pin input/output modes
    SPI_MOSI_TRIS = 0;
    SPI_MISO_TRIS = 1;
    SPI_CLK_TRIS = 0;
    
}
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

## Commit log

2024-01-30 Add initial version of the light link repo
    This initial commit includes the whole project that's mostly completed
    The PCB design has not yet been sent off, but PIC code has been developed
    and tested in a breadboard.
    Tried to nicely organize all components into folders, but probably should
    have done this earlier in the project for better history :)
    [PM2314T02XNT.STEP, PM2314T02XWT.STEP, PM2314T03XNT.STEP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]
2024-01-30 Adding Official RevA0 of the PCB design
    [lightlink-B_Cu.gbl, lightlink-B_Mask.gbs, lightlink-B_Paste.gbp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]
2024-02-09 Add released gerber files and fix board problem with reversed resistors
    [lightlink.kicad_sch, microcontroller_logic.kicad_sch, power.kicad_sch]
2024-02-09 Change behavior of debug LED to show outlet power state
2024-02-26 Fix channel select and remove debug LED flash
    Also update PCB with a few fixes from assembly and test
    [lightlink.kicad_pcb]
2024-03-02 Update PCB with several fixes
    * Increase value of inrush limiting resistor
    * Update locations of button/DIP switch
    * Fix footprint for DIP switch
    * Fix footprint for full bridge rectifier
    * Change 1206 cap footprints to 0805
    * Rotate main JST connector so that it doesn't impact the plug
    [lightlink.kicad_pcb, microcontroller_logic.kicad_sch, power.kicad_sch]
2024-04-03 Update PCB with couple fixes, cleanup code a bit
    [microcontroller_logic.kicad_sch, power.kicad_sch]
2024-04-03 Add a couple images of completed project
2024-04-05 Disable LED blinking and cleanup logging messages a bit
2024-04-29 Refactor LED blink logic and logging a bit
2024-06-18 Fix a few corner cases that may have been causing hangs
    Observed a couple units go unresponsive after a couple weeks of
    power on time without reset. Added a few additional checks and
    improvements to code robustness to hopefully address this.
    Don't have any proof that any of these changes will help for sure,
    but they are more correct and hopefully help recover from corner
    cases.
    [RFM69.c, RFM69.h, main.c]
2024-06-19 Add critical sections around timer code
    Attempt to fix a few potential issues by putting critical section
    around timer access.
    Also add some additional error codes for debug and ability to
    trap an error so it repeatedly blinks last error
    [RFM69.c, config_16F18146.c, config_16F18146.h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]
2024-07-28 Fix bug that caused infinite loop in PLI interrupt
    [RFM69.c, config_16F18146.c, config_16F18146.h]
2024-07-28 Fix timeout values for tx and ack receipt
    [RFM69.h, config_16F18146.c]
2024-12-03 Update the README and add pdf version of SCH
    [lightlink.csv]
